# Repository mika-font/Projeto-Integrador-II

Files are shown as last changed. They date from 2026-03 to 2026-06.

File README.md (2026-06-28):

# Sensor RFID para Controle de Acesso

> Projeto integrante da disciplina Projeto Integrador II — Engenharia de Computação (UFSM).

Sistema de controle de acesso para laboratórios usando leitor RFID conectado a um ESP8266/ESP32. Suporta atualização remota (OTA) e registro básico de eventos.

## Sumário

- [Integrantes](#integrantes)
- [Objetivos](#objetivos)
- [Arquitetura](#arquitetura)
- [Hardware](#hardware)
- [Firmware](#firmware)
- [Instalação](#instalação)
- [Uso](#uso)
- [Estrutura do Projeto](#estrutura-do-projeto)
- [Em desenvolvimento](#em-desenvolvimento)

## Integrantes do Projeto

- Gabriel Schirmer
- Mikael Fontoura
- Raissa Brodt

## Objetivos

Os principais objetivos em desenvolvimento do projeto:

- Controlar o acesso ao laboratório usando um sistema RFID;
- Permitir atualização remota do *firmware* via OTA;
- Registrar eventos de acesso (autorizados e não autorizados);
- Criar uma interface de gerenciamento de tags;

## Arquitetura

Fluxo básico:

1. Tag aproximada ao leitor;
2. Leitor envia ID ao microcontrolador;
3. Microcontrolador verifica autorização;
4. Se autorizado: ativa a fechadura e registra evento;
5. Se não autorizado: registra tentativa e ignora;

## Hardware

Componentes principais:

- ESP8266 ou ESP32
- Leitor RFID (módulo RC522)
- Tags RFID compatíveis
- Fechadura solenóide
- Fonte 12V 3A
- Regulador de Tensão de 12V para 5V (L7805CV)
- Buzzer HNT-1205
- LED Verde e Vermelho
- Transistor TIP31C e Diodo 1N4007
- Resistores (1kΩ)

Pinagem de referência (ESP32):
- `D5` (GPIO2): Saída para relé/fechadura

## Firmware

Versões disponíveis:

- `code-esp8266/code-esp8266.ino` — implementação base para ESP8266
- `code-esp32/code-esp32.ino` — implementação base para ESP32 (Em Funcionamento)

Principais funcionalidades do firmware:

- Leitura de tag RFID via serial
- Lista local de tags autorizadas
- Acionamento da fechadura (pino `D5` no ESP32)
- Atualização OTA (ArduinoOTA)
- Logs básicos por serial (e opcionalmente via rede)

Dependências:

- `WiFi`
- `ArduinoOTA`
- `SPI` 
- `MFRC522`

---

## Instalação

Pré-requisitos:

- Arduino IDE
- Drivers USB (CH340/CP210x) instalados
- Placa ESP8266/ESP32 adicionada no Arduino IDE

Passos rápidos:

1. Abra o Arduino IDE
2. Instale as bibliotecas necessárias via Gerenciador de Placas
3. Para o ESP32, usamos uma URL adicional: "https://espressif.github.io/arduino-esp32/package_esp32_index.json"
4. Após adicionar essa URL, em Gerenciador de Placas, instale a biblioteca do ESP32
5. Selecione a placa apropriada em `Ferramentas → Placa`
6. Abra o código `code-esp8266/code-esp8266.ino` ou `code-esp32/code-esp32.ino`
7. Compile e faça o upload para o dispositivo

Configuração OTA: o firmware habilita `ArduinoOTA` — para usar, conecte o dispositivo à mesma rede do computador e selecione a porta de rede no IDE.

## Uso

1. Energize o sistema com a fonte adequada
2. Aproxime uma tag ao leitor
3. Observe o LED de status e o comportamento do relé
4. Verifique saídas seriais para logs e depuração

---

## Estrutura do Projeto

```
Projeto-Integrador-II/
├── README.md
├── code-esp8266/
├── code-esp32/
├── impressoes/
│   ├── porta_mdf/
│   └── caixas/
├── labflow-ct/
│   ├── backend/
│   ├── database/
│   ├── docs/
│   ├── frontend/
│   └── README.md
└── docs/
```

## Ferramentas Utilizadas

### Hardware e Firmware

- Arduino IDE — desenvolvimento e upload dos sketches
- Drivers USB: CH340 / CP210x
- Bibliotecas ESP32 usadas no firmware: `WiFi.h`, `ArduinoOTA.h`, `SPI.h`, `MFRC522.h` (ver `code-esp32/`)
- Software CAD para arquivos `.SLDPRT` / `.SLDASM`: SolidWorks 2024
- Software para `.DXF` : SolidWorks 2024 (exportação)
- Software para `.STL` : Ultimaker Cura 5.4.0

### Interface, Banco de Dados, Dashboard e Documentação

- Visual Studio Code — desenvolvimento de interface e scripts
- Software para Dashboard: Grafana
- Software para Banco de Dados: (definir)
- FrontEnd: (definir)
- BackEnd: (definir)
- Diagramas e Documentação: LucidChart, Google Docs e Canva

### Demais Ferramentas

- Git e GitHub — controle de versão e hospedagem do código

## Em desenvolvimento

- [x] Firmware base (ESP32)
- [x] Testes de campo com fechadura real
- [ ] Interface de gerenciamento de tags
- [ ] Registro remoto de logs (server)

Se você quiser contribuir, abra uma issue ou envie um pull request.

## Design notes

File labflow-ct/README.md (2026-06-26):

# LabFlow-CT

Software inicial para gerenciamento de cartões, usuários, laboratórios, dispositivos ESP32, permissões, firmware e logs de acesso.

## Stack

- Frontend: React + Vite + Recharts + Socket.IO Client
- Backend: Node.js + Express + MySQL + MQTT + Socket.IO
- Banco: MySQL
- Comunicação ESP32: MQTT

## Estrutura

```text
labflow-ct/
  backend/
  frontend/
  database/schema.sql
  docs/PORTAS_E_MQTT.md
```

## Login inicial

- Matrícula: `admin`
- Senha: `admin123`

Troque essa senha antes de usar em produção.

## Rodar localmente

### Banco

```bash
mysql -u root -p < database/schema.sql
```

Crie um usuário no MySQL, por exemplo:

```sql
CREATE USER 'labflow_user'@'localhost' IDENTIFIED BY 'labflow_pass';
GRANT ALL PRIVILEGES ON labflow_ct.* TO 'labflow_user'@'localhost';
FLUSH PRIVILEGES;
```

### Backend

```bash
cd backend
cp .env.example .env
npm install
npm run dev
```

### Frontend

```bash
cd frontend
cp .env.example .env
npm install
npm run dev
```

### MQTT local

Instale e rode Mosquitto. No Ubuntu:

```bash
sudo apt install mosquitto mosquitto-clients
sudo systemctl enable --now mosquitto
```

## Próximo passo recomendado

Este pacote é um MVP funcional. Para entrega final, recomenda-se complementar as telas de CRUD com formulários completos, validações de campos, upload real dos arquivos `.bin` de firmware e configuração de HTTPS/MQTT TLS.

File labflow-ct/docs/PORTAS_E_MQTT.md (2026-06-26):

# LabFlow-CT — Portas, MQTT e servidor

## Portas de comunicação

| Serviço | Porta padrão | Uso |
|---|---:|---|
| React/Vite em desenvolvimento | 5173 | Interface web local |
| Backend Node.js/Express | 3001 | API REST e WebSocket |
| MySQL | 3306 | Banco de dados |
| MQTT sem TLS | 1883 | Comunicação ESP32 ↔ servidor |
| MQTT com TLS | 8883 | MQTT seguro em produção |
| HTTP | 80 | Acesso público via Nginx |
| HTTPS | 443 | Acesso público seguro via Nginx |

## Tópicos MQTT sugeridos

Use `deviceId` como MAC address sem caracteres especiais ou um ID cadastrado no sistema.

### Pedido de acesso por cartão
ESP32 publica:

```json
Topic: labflow/{deviceId}/access/request
{
  "tokenAuth": "TOKEN_DO_DISPOSITIVO",
  "uid": "E6:97:A7:1A",
  "evento": "RFID_EXTERNO"
}
```

Servidor responde:

```json
Topic: labflow/{deviceId}/access/response
{
  "authorized": true,
  "reason": "PERMISSAO_VALIDA"
}
```

### Evento simples do dispositivo

```json
Topic: labflow/{deviceId}/event
{
  "tokenAuth": "TOKEN_DO_DISPOSITIVO",
  "evento": "BOTAO_EXTERNO_ATIVADO",
  "detalhe": "Modo livre ativado pelo leitor interno"
}
```

Eventos recomendados:

- `RFID_EXTERNO`
- `RFID_INTERNO`
- `BOTAO_EXTERNO`
- `BOTAO_INTERNO`
- `BOTAO_EXTERNO_ATIVADO`
- `BOTAO_EXTERNO_DESATIVADO`
- `STATUS`

### Checagem de firmware

```json
Topic: labflow/{deviceId}/firmware/check
{
  "tokenAuth": "TOKEN_DO_DISPOSITIVO",
  "firmwareAtual": "1.0.0"
}
```

Servidor responde:

```json
Topic: labflow/{deviceId}/firmware/response
{
  "update": true,
  "version": "1.1.0",
  "url": "https://servidor/firmware/labflow-1.1.0.bin",
  "obrigatorio": false
}
```

A regra implementada só libera atualização de firmware entre 00:00 e 06:59, evitando o período de aulas entre 7h e 23h.

## Subida no servidor

1. Instalar Node.js LTS, MySQL, Mosquitto e Nginx.
2. Criar o banco com `database/schema.sql`.
3. Criar usuário MySQL próprio para o projeto.
4. Copiar `backend/.env.example` para `backend/.env` e configurar credenciais.
5. Rodar backend com PM2 ou systemd.
6. Rodar `npm run build` no frontend e servir a pasta `dist` pelo Nginx.
7. Em produção, usar HTTPS na interface e MQTT com autenticação. Se possível, usar MQTT TLS na porta 8883.

## Comandos base Ubuntu Server

```bash
sudo apt update
sudo apt install -y mysql-server mosquitto mosquitto-clients nginx
curl -fsSL https://deb.nodesource.com/setup_lts.x | sudo -E bash -
sudo apt install -y nodejs
sudo npm install -g pm2
```

```bash
mysql -u root -p < database/schema.sql
```

```bash
cd backend
cp .env.example .env
npm install
npm run start
```

```bash
cd frontend
cp .env.example .env
npm install
npm run build
```

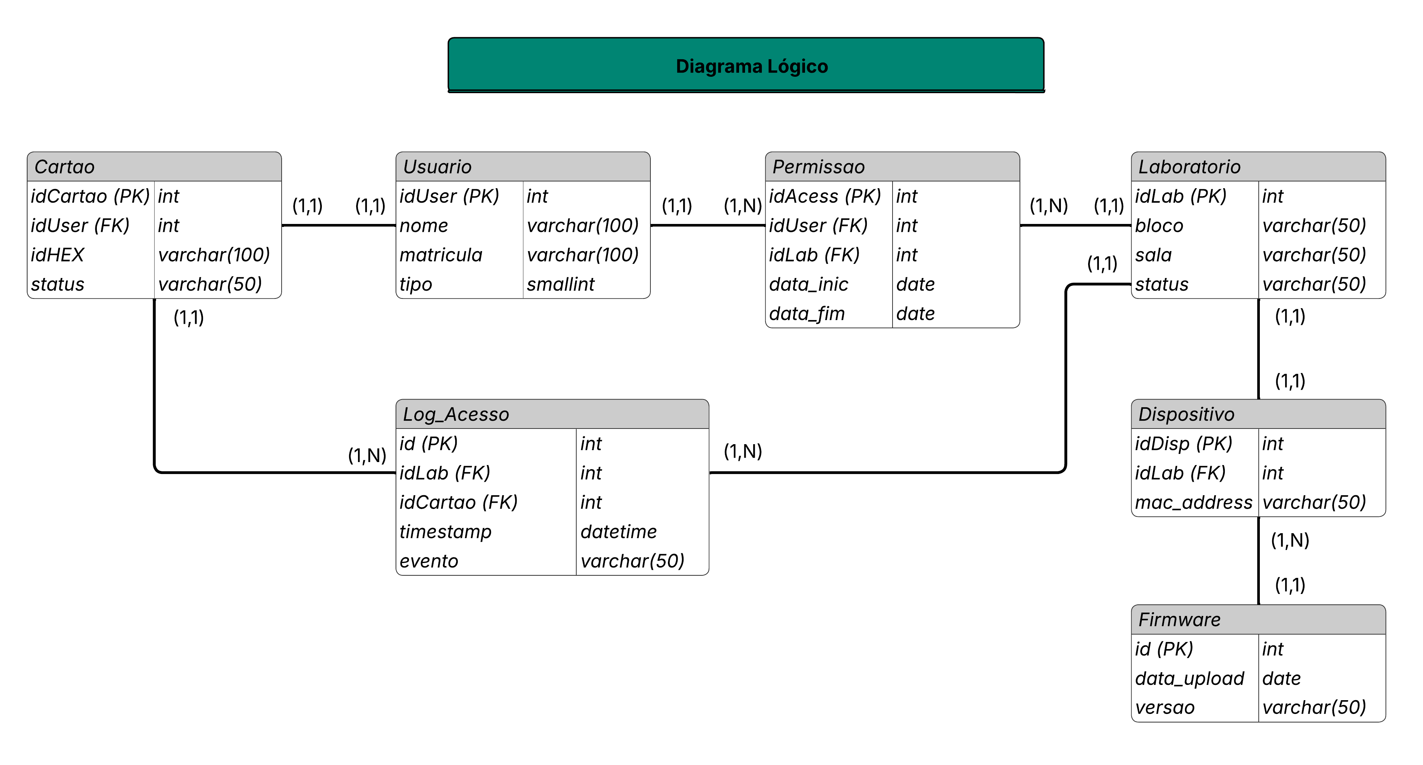
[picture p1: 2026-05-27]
docs/diagrama_Logico_BD.png

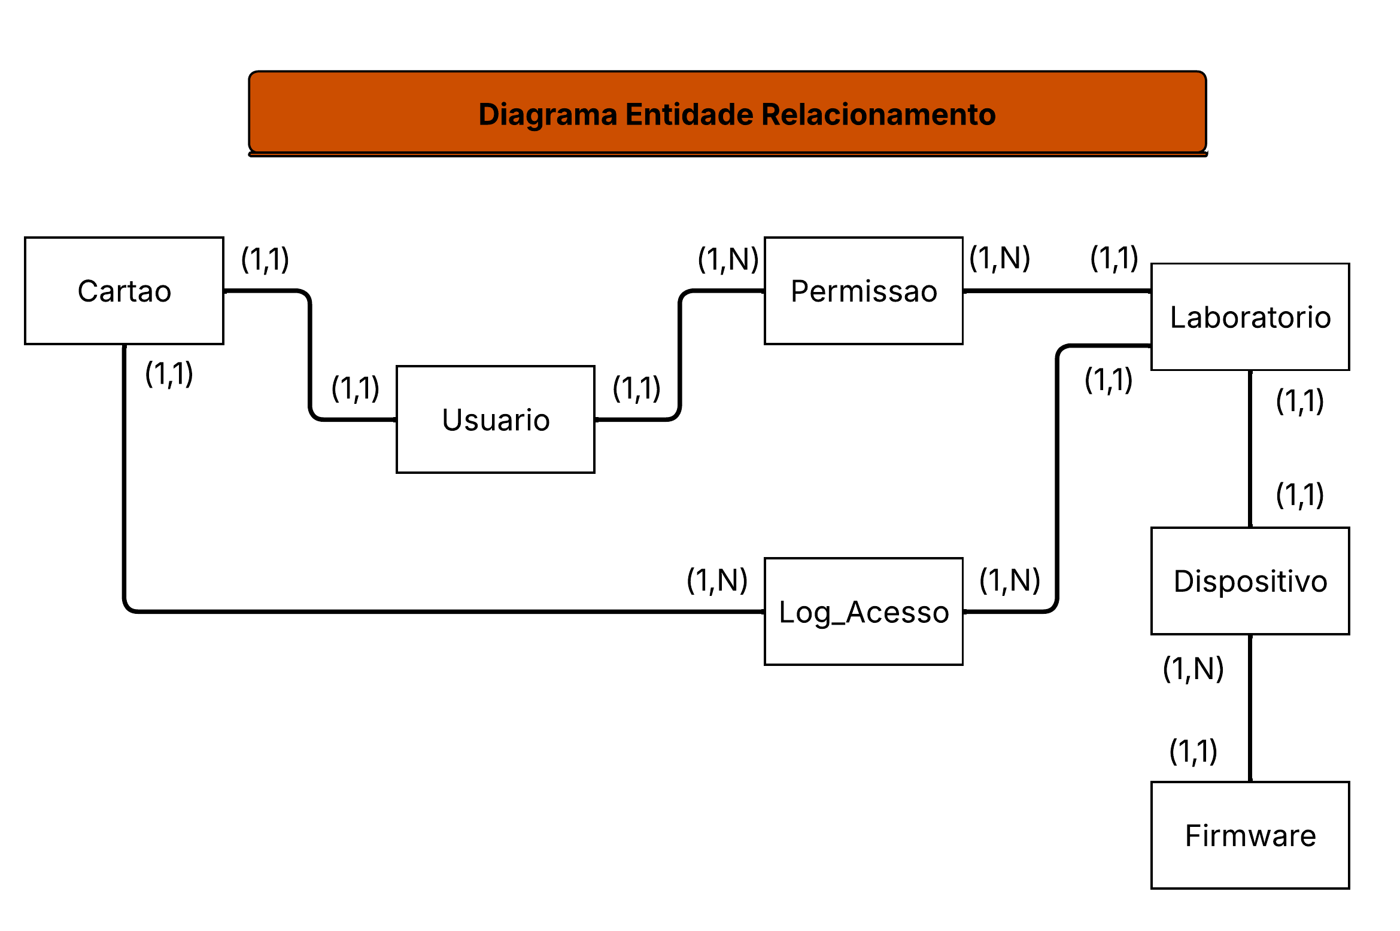
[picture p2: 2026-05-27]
docs/diagrama_Entidade_Relac_BD.png

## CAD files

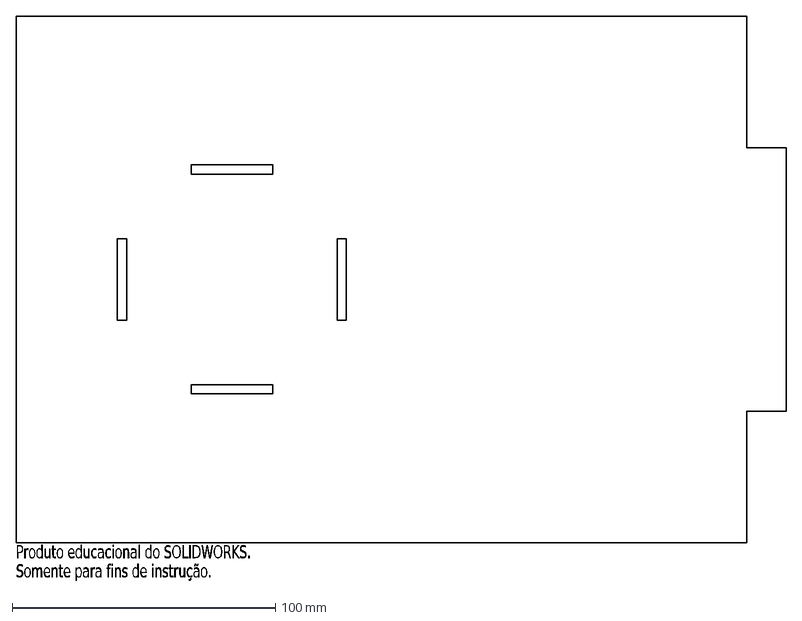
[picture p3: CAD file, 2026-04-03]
impressoes/baseP1.DXF
Produto educacional do SOLIDWORKS.
Somente para fins de instrução.

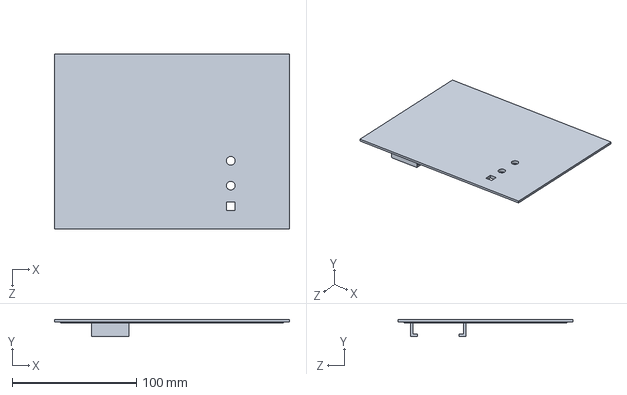
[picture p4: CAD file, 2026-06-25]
impressoes/caixas/tampaCaixaMaior.SLDPRT
189.0 x 14.0 x 141.0 mm

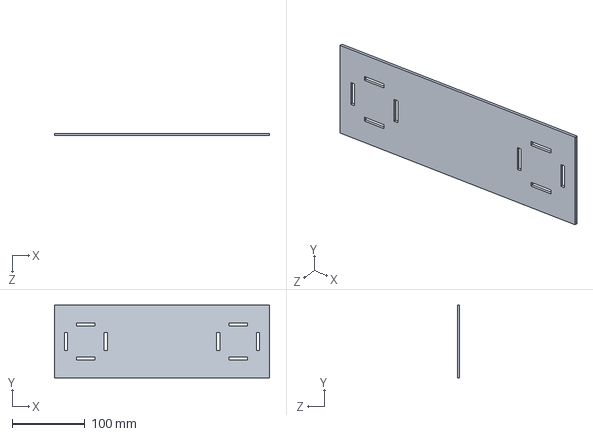
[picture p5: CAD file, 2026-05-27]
impressoes/porta_mdf/base.STEP
295.0 x 100.0 x 3.00 mm

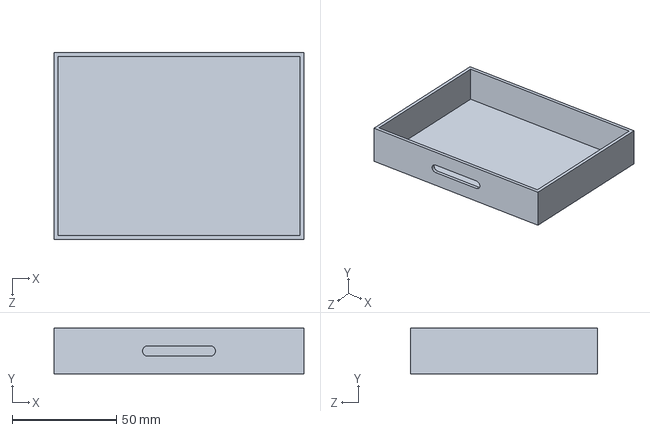
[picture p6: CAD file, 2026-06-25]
impressoes/caixas/caixaMenor.SLDPRT
120.0 x 22.0 x 90.0 mm

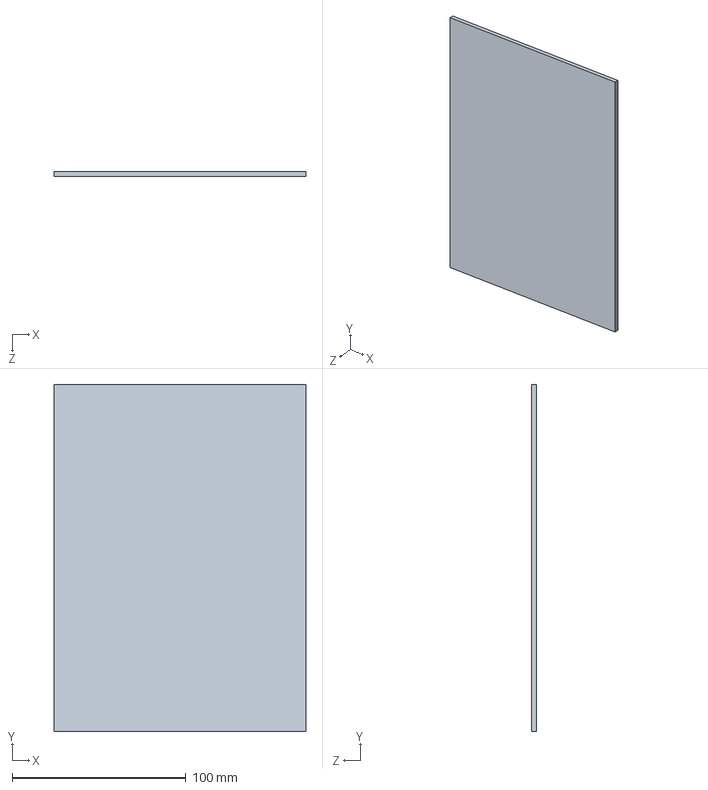
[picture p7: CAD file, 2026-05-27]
impressoes/porta_mdf/porta.STEP
145.0 x 200.0 x 3.00 mm

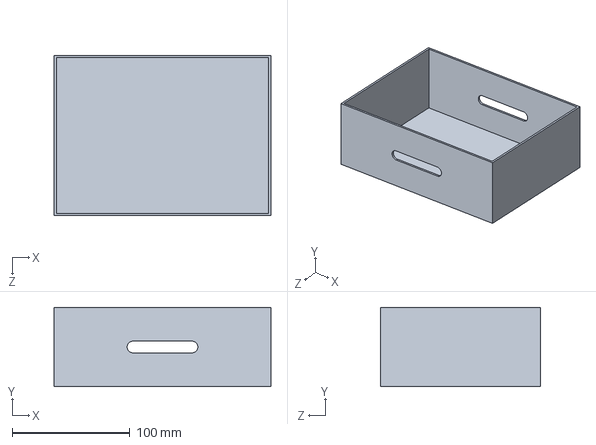
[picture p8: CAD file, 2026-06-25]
impressoes/caixas/caixaMaior.SLDPRT
184.0 x 67.0 x 136.0 mm

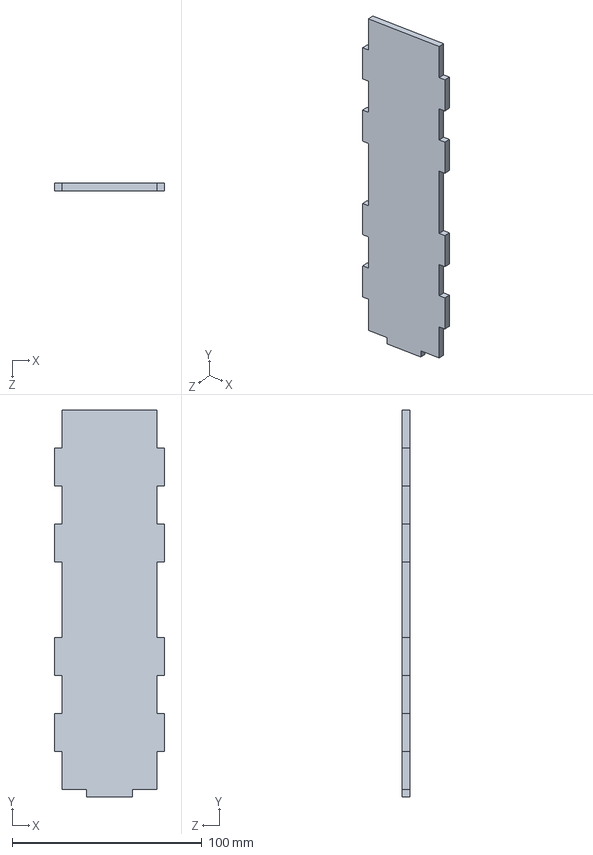
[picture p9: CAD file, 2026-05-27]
impressoes/porta_mdf/colunaDentado.STEP
58.0 x 204.0 x 4.00 mm

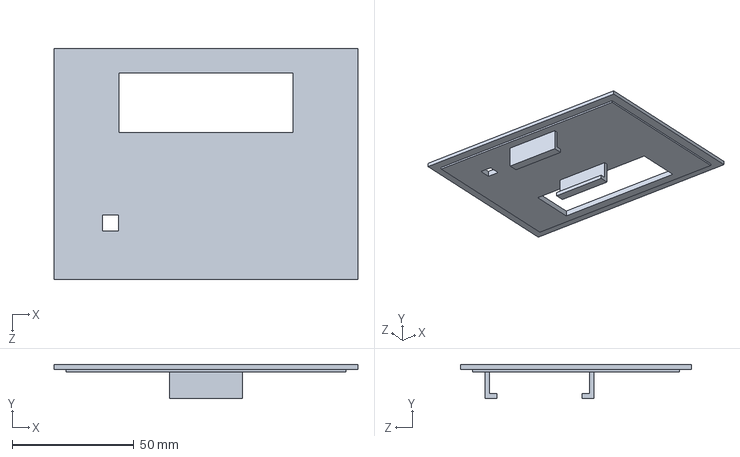
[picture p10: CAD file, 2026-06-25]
impressoes/caixas/tampaCaixaMenor.SLDPRT
125.0 x 14.0 x 95.0 mm

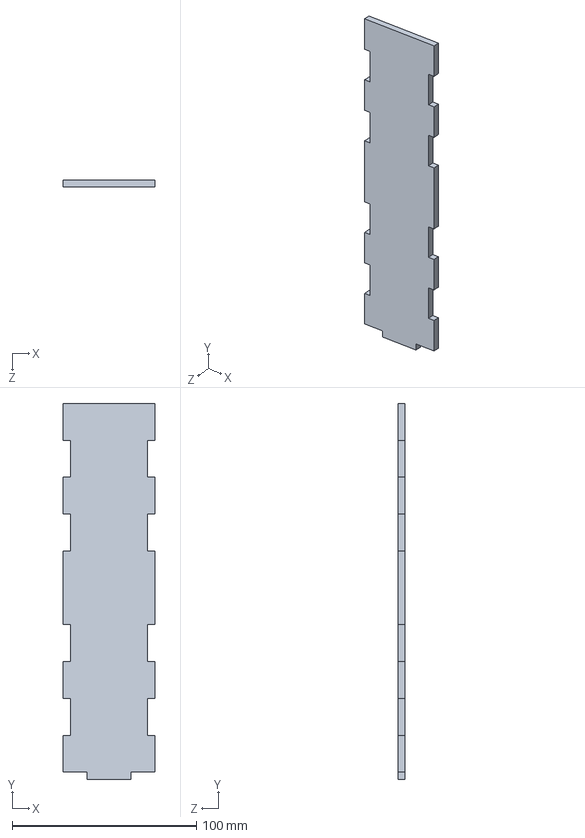
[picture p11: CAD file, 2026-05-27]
impressoes/porta_mdf/colunaVazado.STEP
50.0 x 204.0 x 4.00 mm

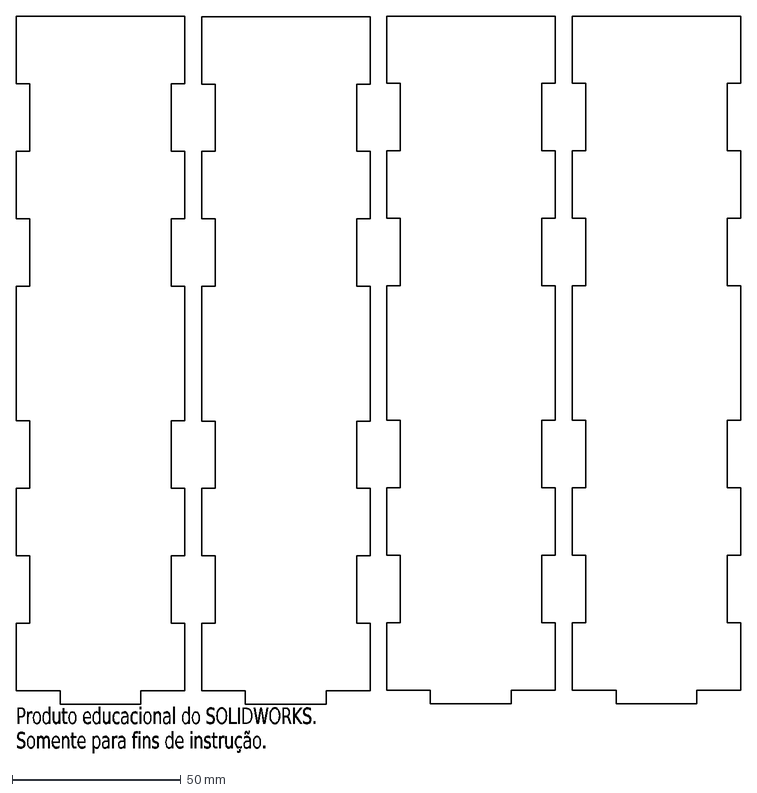
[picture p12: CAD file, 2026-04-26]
impressoes/porta_mdf/mont_4unid_col_vazada.DXF
Produto educacional do SOLIDWORKS.
Somente para fins de instrução.

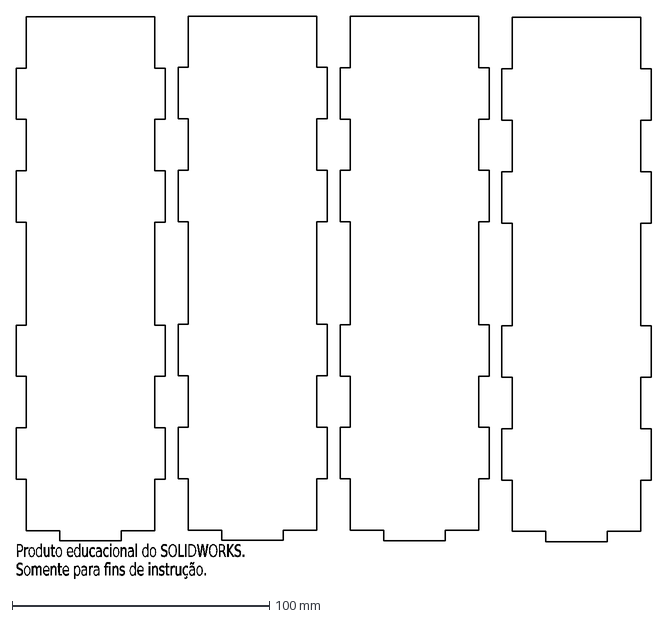
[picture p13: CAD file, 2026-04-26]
impressoes/porta_mdf/mont_4unid_col_dentada.DXF
Produto educacional do SOLIDWORKS.
Somente para fins de instrução.

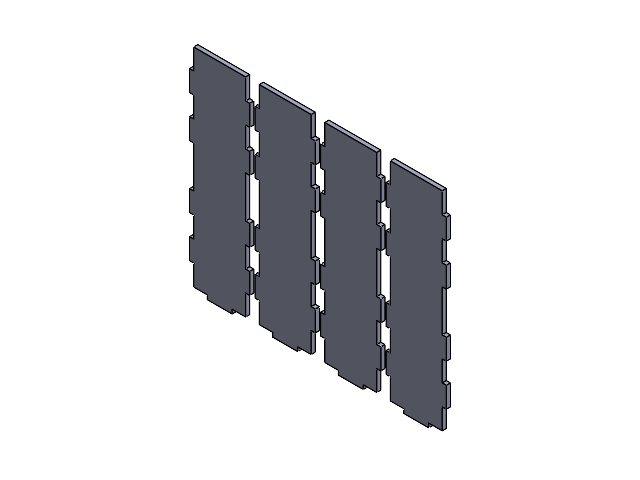
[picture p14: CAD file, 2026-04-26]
impressoes/porta_mdf/mont_colunas_dentadas.SLDASM
colunaDentado x 4

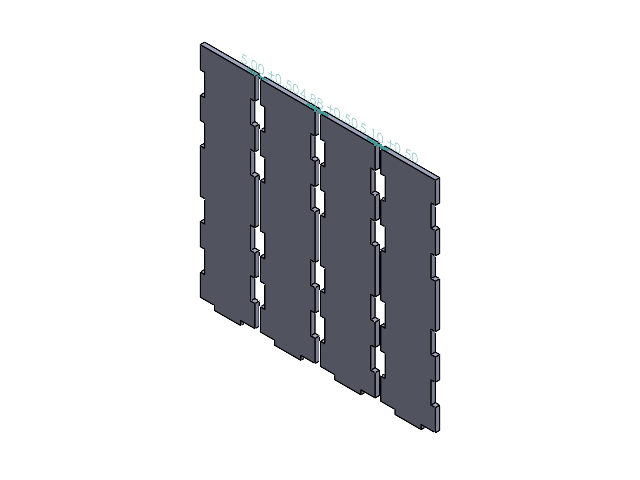
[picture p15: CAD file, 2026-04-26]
impressoes/porta_mdf/mont_colunas_vazadas.SLDASM
colunaVazado x 4

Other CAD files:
impressoes/caixas/caixaMaior.STL
impressoes/caixas/caixaMenor.STL
impressoes/caixas/tampaCaixaMaior.STL
impressoes/caixas/tampaCaixaMenor.STL
impressoes/porta_mdf/base.DXF
impressoes/porta_mdf/base.SLDPRT
impressoes/porta_mdf/colunaDentado.DXF
impressoes/porta_mdf/colunaDentado.SLDPRT
impressoes/porta_mdf/colunaVazado.DXF
impressoes/porta_mdf/colunaVazado.SLDPRT
impressoes/porta_mdf/porta.DXF
impressoes/porta_mdf/porta.SLDPRT

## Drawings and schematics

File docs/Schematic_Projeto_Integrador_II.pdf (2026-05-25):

A | A

1

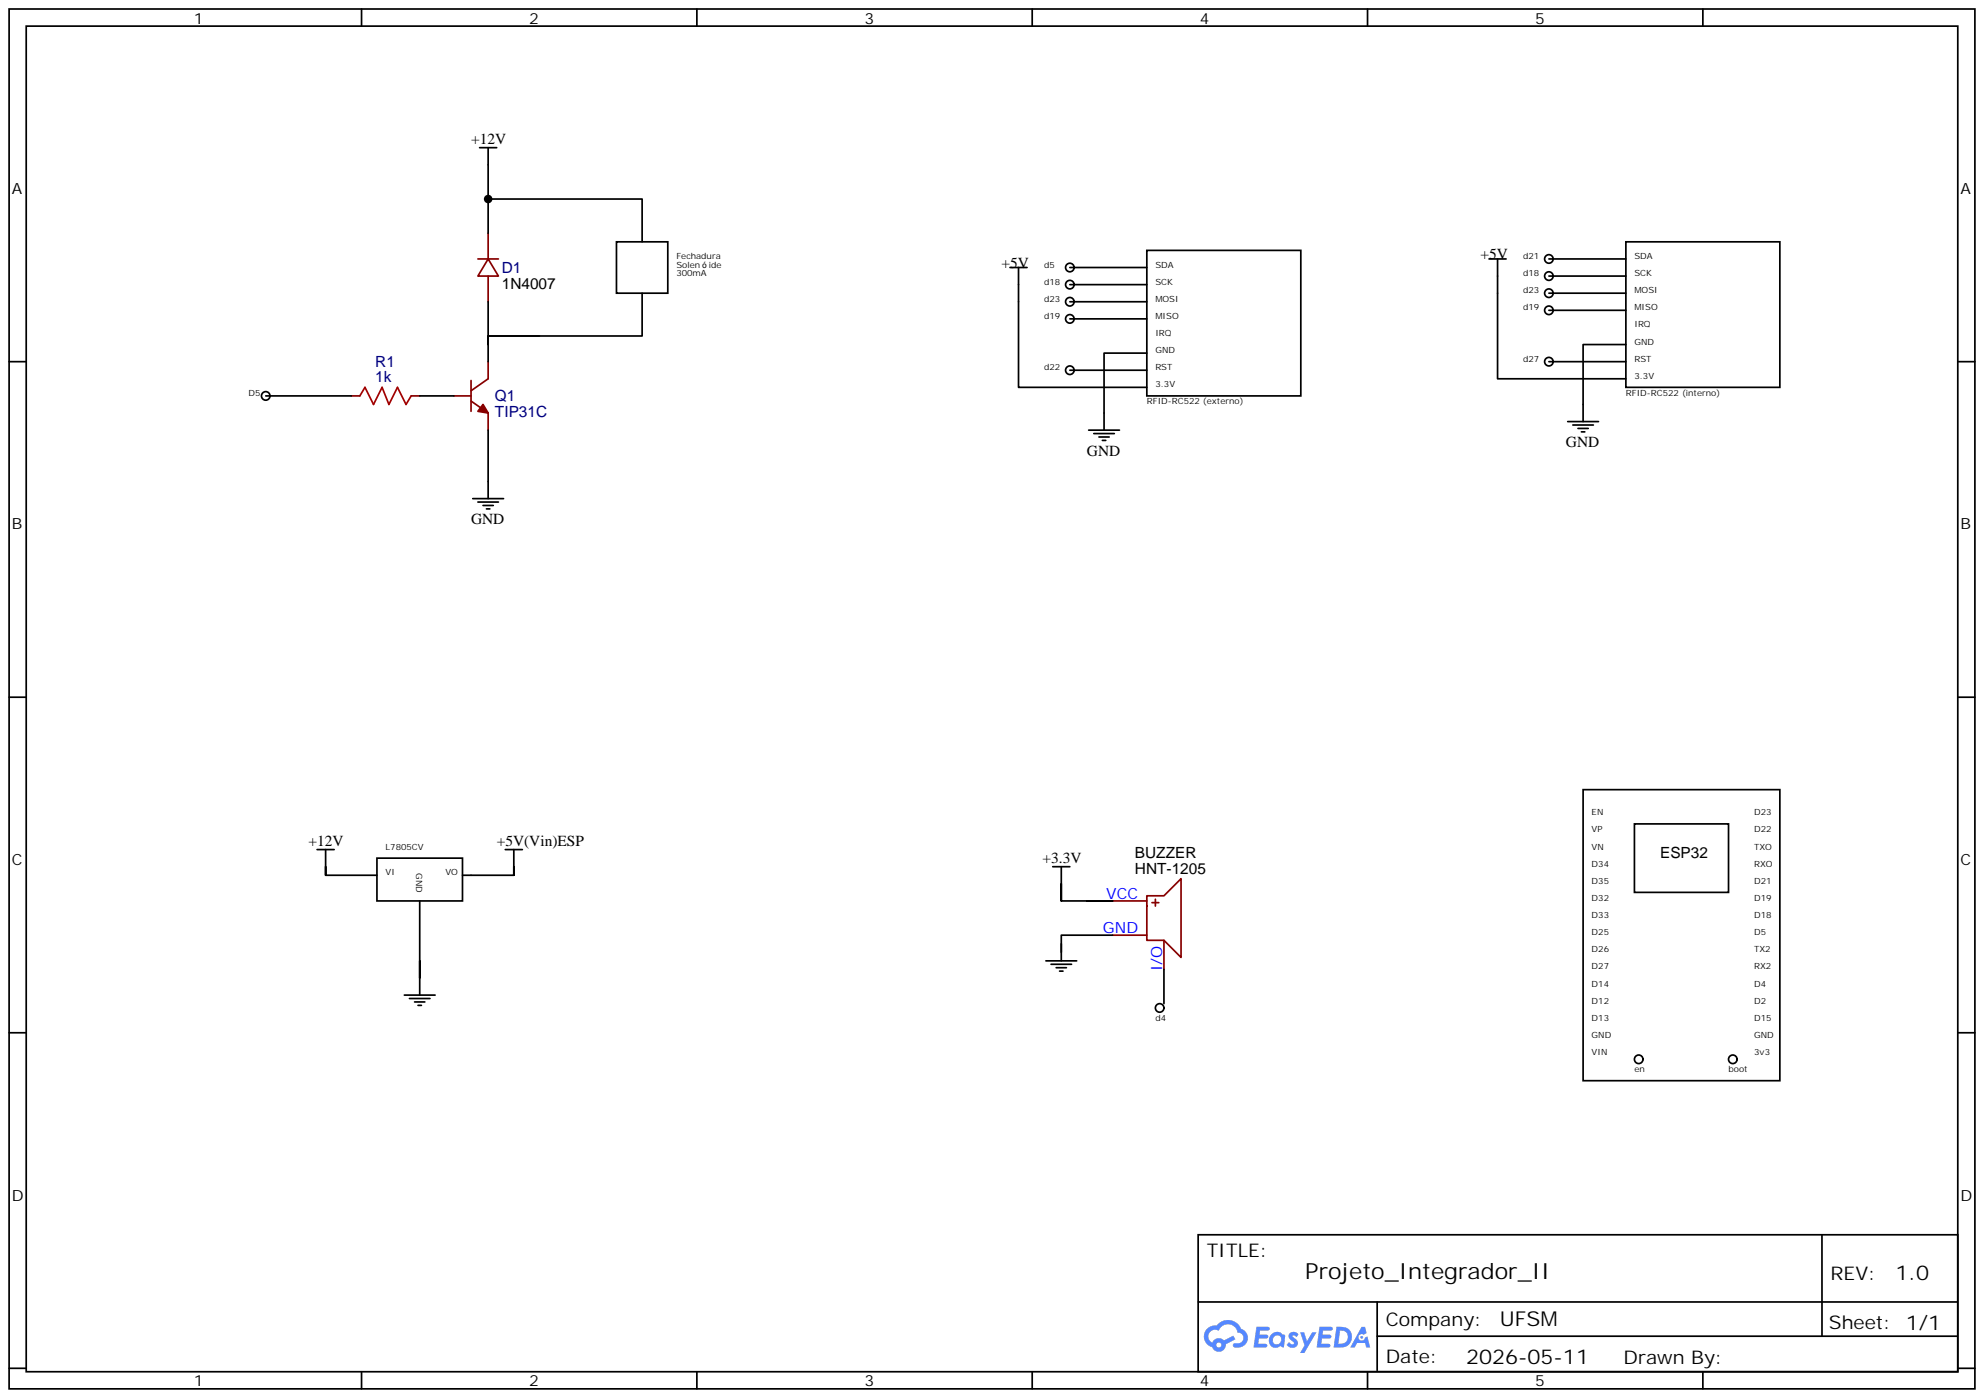
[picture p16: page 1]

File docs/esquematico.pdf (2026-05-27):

A | A

1

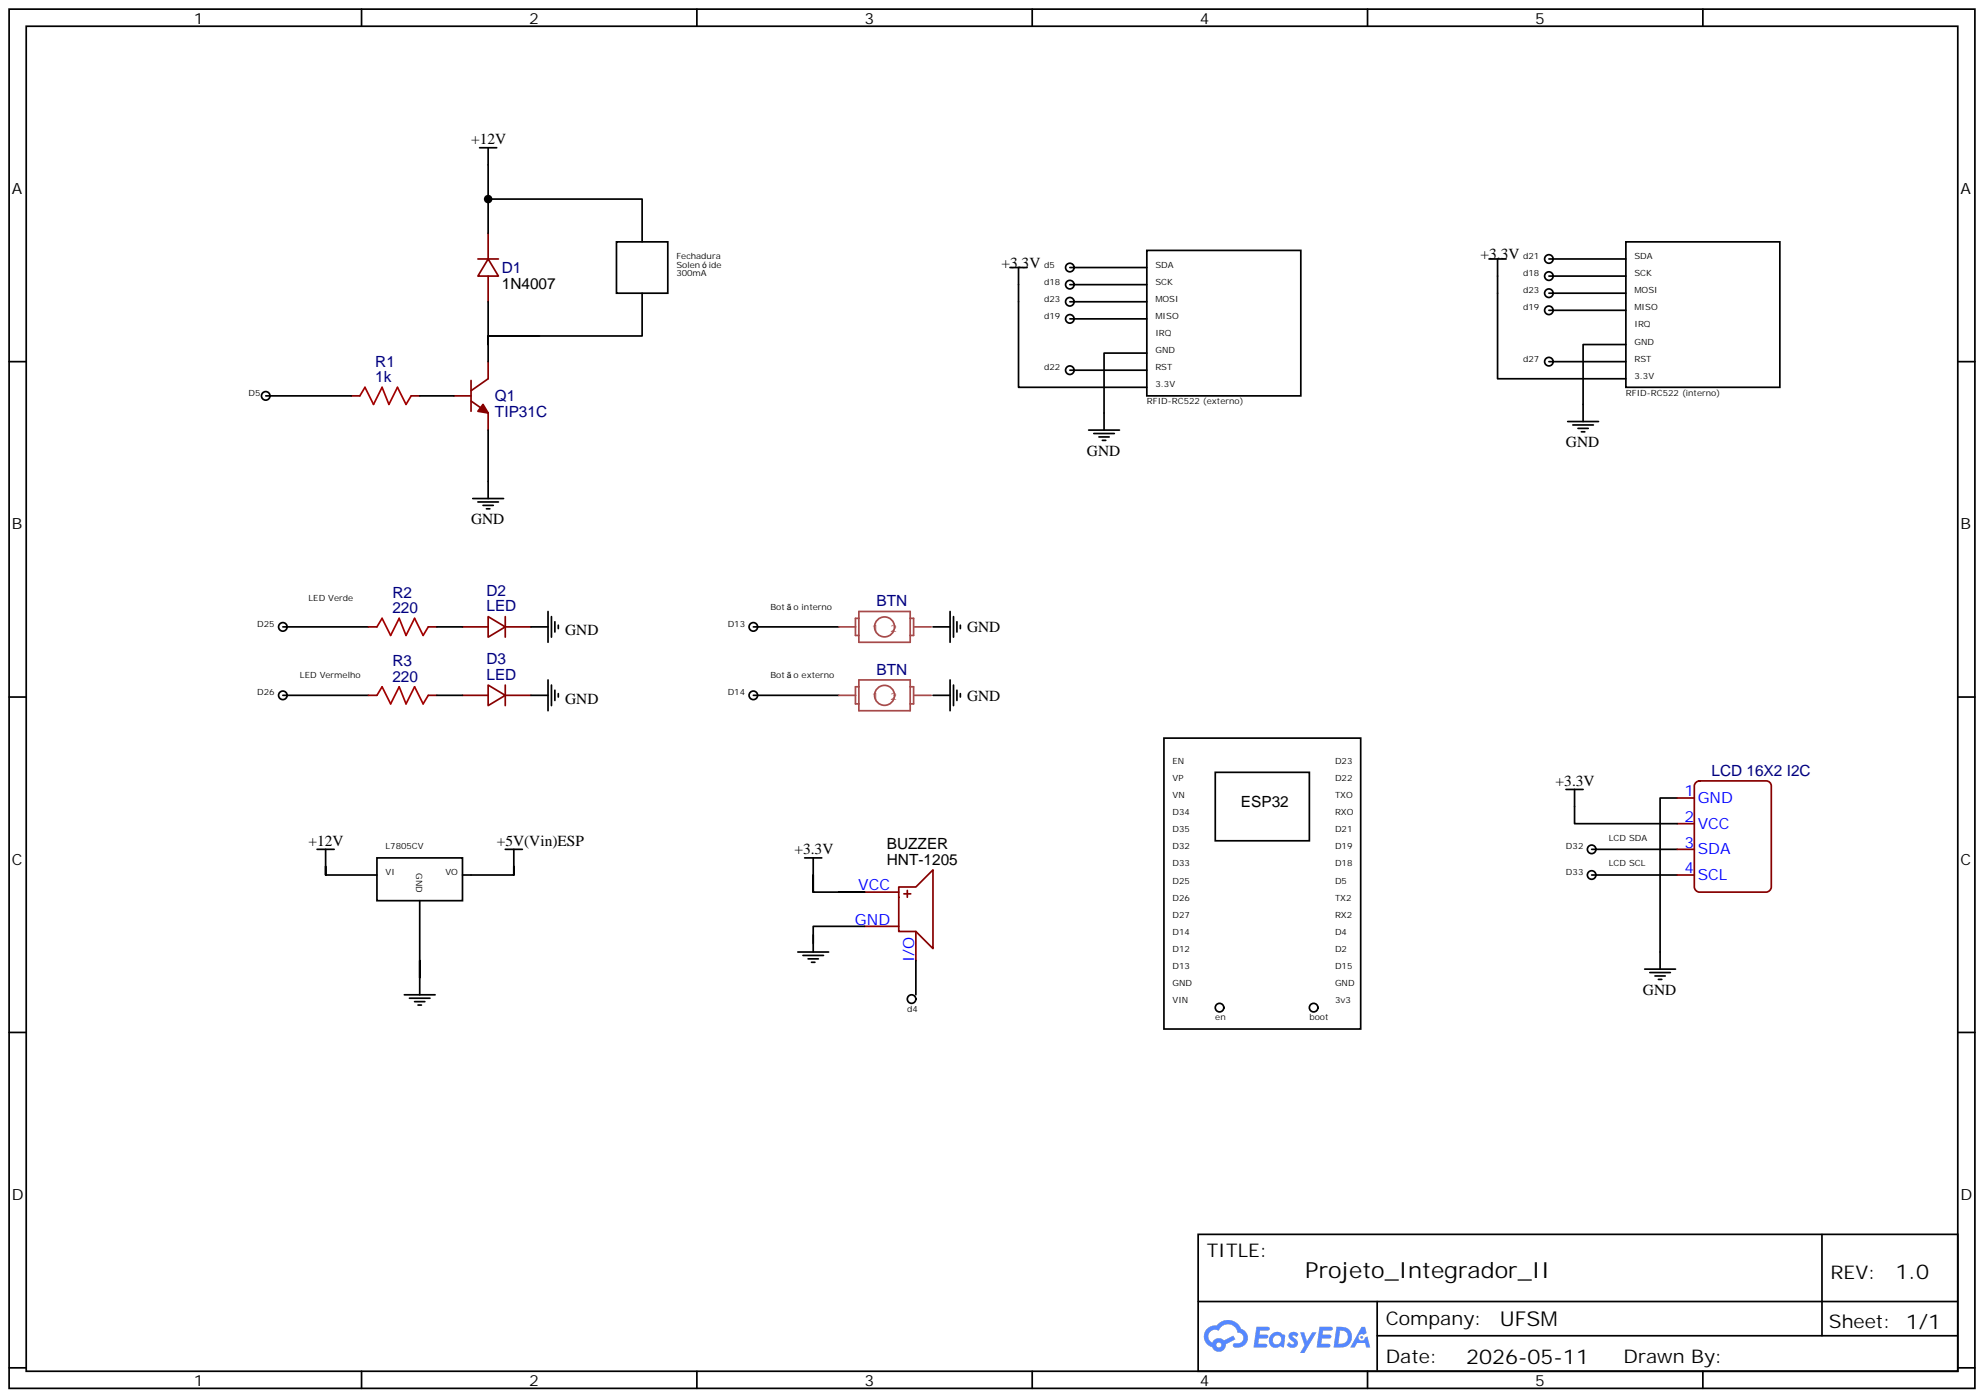
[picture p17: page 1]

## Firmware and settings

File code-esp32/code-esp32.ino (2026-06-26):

#include <WiFi.h>
#include <ArduinoOTA.h>
#include <SPI.h>
#include <MFRC522.h>
#include <Wire.h>
#include <LiquidCrystal_I2C.h>

#include <PubSubClient.h>
#include <ArduinoJson.h>

// ======================================================
// MQTT
// ======================================================
const char* mqtt_server = "192.168.3.23"; // IP do computador/servidor local
const int mqtt_port = 1883;

const char* deviceId = "1";
const char* tokenAuth = "labflow-token-esp32-001";

WiFiClient espClient;
PubSubClient mqtt(espClient);

// ======================================================
// LCD
// ======================================================
LiquidCrystal_I2C lcd(0x27, 16, 2);

// ======================================================
// WIFI
// ======================================================
const char* ssid = "Schirmer";
const char* password = "g254156325";

// ======================================================
// RFID EXTERNO
// ======================================================
#define SS_PIN_EXT 5
#define RST_PIN_EXT 22
MFRC522 rfidExt(SS_PIN_EXT, RST_PIN_EXT);

// ======================================================
// RFID INTERNO
// ======================================================
#define SS_PIN_INT 21
#define RST_PIN_INT 27
MFRC522 rfidInt(SS_PIN_INT, RST_PIN_INT);

// ======================================================
// BUZZER
// ======================================================
#define BUZZER 4

// ======================================================
// LEDS
// ======================================================
#define LED_GREEN 25
#define LED_RED   26

// ======================================================
// BOTÕES
// ======================================================
#define BUTTON 14       // Botão externo
#define BUTTON_EXIT 13  // Botão interno

// ======================================================
// FECHADURA
// ======================================================
#define LOCK 2 // GPIO da fechadura

// ======================================================
// CARTÃO UNIVERSAL
// ======================================================
const String CARTAO_UNIVERSAL = "F5 E2 39 D5"; // NUPEEDE

// ======================================================
// ESTADO
// ======================================================
bool modoLivre = false;
String ultimaOrigemConsulta = "";

// ======================================================
// CONTROLE DE LEITURA REPETIDA RFID
// ======================================================
String ultimoUIDLido = "";
String ultimoLeitorLido = "";
unsigned long tempoUltimaLeitura = 0;
const unsigned long intervaloMesmoCartao = 3000; // 3 segundos

// ======================================================
// PROTÓTIPOS
// ======================================================
void atualizarLCD();
void atualizarLEDs();
void bipCurto();
void bipErro();
void abrirPorta();
void conectarMQTT();
void enviarEvento(String evento, String descricao);
void enviarTentativaAcesso(String uidHex, String origem);
String uidToString(byte *uid, byte size);
bool leituraRepetida(String uidHex, String leitor);
void alternarModoLivre(String origem);
void mqttCallback(char* topic, byte* payload, unsigned int length);

// ======================================================
// FUNÇÕES DE INTERFACE
// ======================================================
void atualizarLEDs() {
  if (modoLivre) {
    digitalWrite(LED_GREEN, HIGH);
    digitalWrite(LED_RED, LOW);
  } else {
    digitalWrite(LED_GREEN, LOW);
    digitalWrite(LED_RED, HIGH);
  }
}

void atualizarLCD() {
  lcd.clear();

  if (modoLivre) {
    lcd.setCursor(0, 0);
    lcd.print("SALA ABERTA");

    lcd.setCursor(0, 1);
    lcd.print("Botao Liberado");
  } else {
    lcd.setCursor(0, 0);
    lcd.print("SALA FECHADA");

    lcd.setCursor(0, 1);
    lcd.print("Aguardando...");
  }
}

void bipCurto() {
  digitalWrite(BUZZER, LOW);
  delay(200);
  digitalWrite(BUZZER, HIGH);
}

void bipErro() {
  for (int i = 0; i < 2; i++) {
    digitalWrite(BUZZER, LOW);
    delay(150);
    digitalWrite(BUZZER, HIGH);
    delay(150);
  }
}

void abrirPorta() {
  bipCurto();

  lcd.clear();
  lcd.setCursor(0, 0);
  lcd.print("PORTA ABERTA");

  lcd.setCursor(0, 1);
  lcd.print("Acesso Liberado");

  digitalWrite(LOCK, HIGH);

  delay(3000);

  digitalWrite(LOCK, LOW);

  atualizarLCD();
}

void alternarModoLivre(String origem) {
  modoLivre = !modoLivre;

  atualizarLEDs();

  lcd.clear();

  if (modoLivre) {
    Serial.println("MODO LIVRE ATIVADO");

    lcd.setCursor(0, 0);
    lcd.print("SALA ABERTA");

    lcd.setCursor(0, 1);
    lcd.print(origem);
  } else {
    Serial.println("MODO LIVRE DESATIVADO");

    lcd.setCursor(0, 0);
    lcd.print("SALA FECHADA");

    lcd.setCursor(0, 1);
    lcd.print(origem);
  }

  bipCurto();

  delay(1000);
  atualizarLCD();
}

// ======================================================
// FUNÇÕES RFID
// ======================================================
String uidToString(byte *uid, byte size) {
  String uidString = "";

  for (byte i = 0; i < size; i++) {
    if (uid[i] < 0x10) {
      uidString += "0";
    }

    uidString += String(uid[i], HEX);

    if (i < size - 1) {
      uidString += " ";
    }
  }

  uidString.toUpperCase();
  return uidString;
}

bool leituraRepetida(String uidHex, String leitor) {
  unsigned long agora = millis();

  if (uidHex == ultimoUIDLido &&
      leitor == ultimoLeitorLido &&
      agora - tempoUltimaLeitura < intervaloMesmoCartao) {
    Serial.println("Leitura repetida ignorada");
    return true;
  }

  ultimoUIDLido = uidHex;
  ultimoLeitorLido = leitor;
  tempoUltimaLeitura = agora;

  return false;
}

// ======================================================
// MQTT
// ======================================================
void conectarMQTT() {
  while (!mqtt.connected()) {
    Serial.print("Conectando ao MQTT... ");

    String clientId = "ESP32-LabFlow-" + String(deviceId);

    if (mqtt.connect(clientId.c_str())) {
      Serial.println("conectado!");

      String responseTopic = "labflow/" + String(deviceId) + "/access/response";
      mqtt.subscribe(responseTopic.c_str());

      String firmwareTopic = "labflow/" + String(deviceId) + "/firmware/response";
      mqtt.subscribe(firmwareTopic.c_str());

      String statusTopic = "labflow/" + String(deviceId) + "/status";

      StaticJsonDocument<128> doc;
      doc["tokenAuth"] = tokenAuth;
      doc["status"] = "ONLINE";

      char buffer[128];
      serializeJson(doc, buffer);

      mqtt.publish(statusTopic.c_str(), buffer);

      Serial.print("Inscrito em: ");
      Serial.println(responseTopic);

    } else {
      Serial.print("falhou. Codigo: ");
      Serial.println(mqtt.state());
      delay(3000);
    }
  }
}

void enviarEvento(String evento, String descricao) {
  if (!mqtt.connected()) {
    conectarMQTT();
  }

  StaticJsonDocument<256> doc;

  doc["tokenAuth"] = tokenAuth;
  doc["evento"] = evento;
  doc["descricao"] = descricao;

  char buffer[256];
  serializeJson(doc, buffer);

  String topic = "labflow/" + String(deviceId) + "/event";

  mqtt.publish(topic.c_str(), buffer);

  Serial.print("Evento enviado para ");
  Serial.print(topic);
  Serial.print(": ");
  Serial.println(buffer);
}

void enviarTentativaAcesso(String uidHex, String origem) {
  if (!mqtt.connected()) {
    conectarMQTT();
  }

  ultimaOrigemConsulta = origem;

  StaticJsonDocument<256> doc;

  doc["tokenAuth"] = tokenAuth;
  doc["uid"] = uidHex;
  doc["origem"] = origem;
  doc["evento"] = origem;

  char buffer[256];
  serializeJson(doc, buffer);

  String topic = "labflow/" + String(deviceId) + "/access/request";

  mqtt.publish(topic.c_str(), buffer);

  Serial.print("Tentativa enviada para ");
  Serial.print(topic);
  Serial.print(": ");
  Serial.println(buffer);

  lcd.clear();
  lcd.setCursor(0, 0);
  lcd.print("Verificando...");

  lcd.setCursor(0, 1);
  if (origem == "RFID_INTERNO") {
    lcd.print("Cartao Interno");
  } else {
    lcd.print("Cartao Externo");
  }
}

void mqttCallback(char* topic, byte* payload, unsigned int length) {
  String mensagem;

  for (unsigned int i = 0; i < length; i++) {
    mensagem += (char)payload[i];
  }

  Serial.print("Mensagem recebida em ");
  Serial.print(topic);
  Serial.print(": ");
  Serial.println(mensagem);

  StaticJsonDocument<256> doc;
  DeserializationError erro = deserializeJson(doc, mensagem);

  if (erro) {
    Serial.println("Erro ao interpretar JSON MQTT");
    return;
  }

  String topico = String(topic);

  if (topico.endsWith("/access/response")) {
    bool authorized = doc["authorized"] | false;
    const char* reason = doc["reason"] | "";

    Serial.print("Resposta acesso: ");
    Serial.println(reason);

    if (authorized) {
      if (ultimaOrigemConsulta == "RFID_EXTERNO") {
        Serial.println("SERVIDOR LIBEROU RFID EXTERNO");

        lcd.clear();
        lcd.setCursor(0, 0);
        lcd.print("ACESSO LIBERADO");
        lcd.setCursor(0, 1);
        lcd.print("Servidor OK");

        abrirPorta();

      } else if (ultimaOrigemConsulta == "RFID_INTERNO") {
        Serial.println("SERVIDOR LIBEROU RFID INTERNO");

        alternarModoLivre("Servidor OK");

      } else {
        Serial.println("Origem desconhecida na resposta MQTT");
      }

    } else {
      Serial.println("SERVIDOR NEGOU ACESSO");

      lcd.clear();
      lcd.setCursor(0, 0);
      lcd.print("ACESSO NEGADO");

      lcd.setCursor(0, 1);
      lcd.print(reason);

      bipErro();

      delay(1000);
      atualizarLCD();
    }

    ultimaOrigemConsulta = "";
  }
}

// ======================================================
// SETUP
// ======================================================
void setup() {
  Serial.begin(9600);

  // LCD
  Wire.begin(32, 33);

  lcd.init();
  lcd.backlight();

  lcd.setCursor(0, 0);
  lcd.print("Sistema OK");

  // Buzzer
  pinMode(BUZZER, OUTPUT);
  digitalWrite(BUZZER, HIGH);

  // Fechadura
  pinMode(LOCK, OUTPUT);
  digitalWrite(LOCK, LOW);

  // LEDs
  pinMode(LED_GREEN, OUTPUT);
  pinMode(LED_RED, OUTPUT);

  // Botões
  pinMode(BUTTON, INPUT_PULLUP);
  pinMode(BUTTON_EXIT, INPUT_PULLUP);

  atualizarLEDs();

  // SPI padrão do ESP32
  // SCK = 18
  // MISO = 19
  // MOSI = 23
  SPI.begin();

  // Configura SS dos dois leitores
  pinMode(SS_PIN_EXT, OUTPUT);
  pinMode(SS_PIN_INT, OUTPUT);

  // Desativa ambos inicialmente
  digitalWrite(SS_PIN_EXT, HIGH);
  digitalWrite(SS_PIN_INT, HIGH);

  // Inicializa RFID externo
  digitalWrite(SS_PIN_EXT, LOW);
  rfidExt.PCD_Init();
  digitalWrite(SS_PIN_EXT, HIGH);

  // Inicializa RFID interno
  digitalWrite(SS_PIN_INT, LOW);
  rfidInt.PCD_Init();
  digitalWrite(SS_PIN_INT, HIGH);

  Serial.println("Sistema iniciado");

  // Wi-Fi
  WiFi.begin(ssid, password);
  Serial.print("Conectando WiFi");

  while (WiFi.status() != WL_CONNECTED) {
    delay(500);
    Serial.print(".");
  }

  Serial.println();
  Serial.println("WiFi conectado!");
  Serial.print("IP da ESP32: ");
  Serial.println(WiFi.localIP());

  // MQTT
  mqtt.setServer(mqtt_server, mqtt_port);
  mqtt.setCallback(mqttCallback);

  conectarMQTT();

  // OTA
  ArduinoOTA.setPassword("srm");
  ArduinoOTA.begin();

  Serial.println("OTA pronto!");

  // LCD inicial
  lcd.clear();

  lcd.setCursor(0, 0);
  lcd.print("WiFi OK");

  lcd.setCursor(0, 1);
  lcd.print(WiFi.localIP());

  delay(5000);
  atualizarLCD();
}

// ======================================================
// LOOP
// ======================================================
void loop() {
  ArduinoOTA.handle();

  if (!mqtt.connected()) {
    conectarMQTT();
  }

  mqtt.loop();

  // ====================================================
  // TESTA RFID INTERNO
  // ====================================================
  digitalWrite(SS_PIN_EXT, HIGH);
  digitalWrite(SS_PIN_INT, LOW);

  if (rfidInt.PICC_IsNewCardPresent() && rfidInt.PICC_ReadCardSerial()) {
    String uidHex = uidToString(rfidInt.uid.uidByte, rfidInt.uid.size);

    Serial.print("UID interno: ");
    Serial.println(uidHex);

    if (leituraRepetida(uidHex, "RFID_INTERNO")) {
      rfidInt.PICC_HaltA();
      rfidInt.PCD_StopCrypto1();
      digitalWrite(SS_PIN_INT, HIGH);
      return;
    }

    if (uidHex == CARTAO_UNIVERSAL) {
      Serial.println("CARTAO UNIVERSAL NO RFID INTERNO");

      alternarModoLivre("Cartao Universal");

    } else {
      enviarTentativaAcesso(uidHex, "RFID_INTERNO");
    }

    rfidInt.PICC_HaltA();
    rfidInt.PCD_StopCrypto1();
  }

  digitalWrite(SS_PIN_INT, HIGH);

  // ====================================================
  // BOTÃO EXTERNO
  // Funciona apenas se modoLivre estiver ativo
  // ====================================================
  if (modoLivre && digitalRead(BUTTON) == LOW) {
    Serial.println("BOTAO EXTERNO PRESSIONADO");

    enviarEvento("BOTAO_EXTERNO", "Porta aberta pelo botao externo em modo livre");

    abrirPorta();

    while (digitalRead(BUTTON) == LOW) {
      delay(10);
    }

    delay(200);
  }

  // ====================================================
  // BOTÃO INTERNO
  // Sempre abre a porta
  // ====================================================
  if (digitalRead(BUTTON_EXIT) == LOW) {
    Serial.println("BOTAO INTERNO PRESSIONADO");

    enviarEvento("BOTAO_INTERNO", "Porta aberta pelo botao interno");

    abrirPorta();

    while (digitalRead(BUTTON_EXIT) == LOW) {
      delay(10);
    }

    delay(200);
  }

  // ====================================================
  // TESTA RFID EXTERNO
  // ====================================================
  digitalWrite(SS_PIN_INT, HIGH);
  digitalWrite(SS_PIN_EXT, LOW);

  if (rfidExt.PICC_IsNewCardPresent() && rfidExt.PICC_ReadCardSerial()) {
    String uidHex = uidToString(rfidExt.uid.uidByte, rfidExt.uid.size);

    Serial.print("UID externo: ");
    Serial.println(uidHex);

    if (leituraRepetida(uidHex, "RFID_EXTERNO")) {
      rfidExt.PICC_HaltA();
      rfidExt.PCD_StopCrypto1();
      digitalWrite(SS_PIN_EXT, HIGH);
      return;
    }

    if (uidHex == CARTAO_UNIVERSAL) {
      Serial.println("CARTAO UNIVERSAL NO RFID EXTERNO");

      lcd.clear();
      lcd.setCursor(0, 0);
      lcd.print("ACESSO LIBERADO");

      lcd.setCursor(0, 1);
      lcd.print("Cartao Universal");

      abrirPorta();

      delay(1000);
      atualizarLCD();

    } else {
      enviarTentativaAcesso(uidHex, "RFID_EXTERNO");
    }

    rfidExt.PICC_HaltA();
    rfidExt.PCD_StopCrypto1();
  }

  digitalWrite(SS_PIN_EXT, HIGH);
}

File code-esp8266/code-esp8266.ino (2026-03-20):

#include <ESP8266WiFi.h>
#include <ESP8266mDNS.h>
#include <WiFiUdp.h>
#include <ArduinoOTA.h>

const char* ssid = "TauraBots";
const char* password = "robotica2024";

void setup() {
  pinMode(D4, OUTPUT);
  Serial.begin(115200);
  Serial.println("Iniciando...");
  WiFi.mode(WIFI_STA);
  WiFi.begin(ssid, password);
  while (WiFi.waitForConnectResult() != WL_CONNECTED) {
    Serial.println("Conexao falhou! Reiniciando...");
    delay(5000);
    ESP.restart();
  }

  ArduinoOTA.onStart([]() {
    Serial.println("Inicio...");
  });
  ArduinoOTA.onEnd([]() {
    Serial.println("nFim!");
  });
  ArduinoOTA.onProgress([](unsigned int progress, unsigned int total) {
    Serial.printf("Progresso: %u%%r", (progress / (total / 100)));
  });
  ArduinoOTA.onError([](ota_error_t error) {
    Serial.printf("Erro [%u]: ", error);
    if (error == OTA_AUTH_ERROR) Serial.println("Autenticacao Falhou");
    else if (error == OTA_BEGIN_ERROR) Serial.println("Falha no Inicio");
    else if (error == OTA_CONNECT_ERROR) Serial.println("Falha na Conexao");
    else if (error == OTA_RECEIVE_ERROR) Serial.println("Falha na Recepcao");
    else if (error == OTA_END_ERROR) Serial.println("Falha no Fim");
  });
  ArduinoOTA.begin();
  Serial.println("Pronto");
  Serial.print("Endereco IP: ");
  Serial.println(WiFi.localIP());
}

void loop() {
  ArduinoOTA.handle();
  digitalWrite(D4, HIGH); // Aciona sinal 2
  delay(2000); // Espera por 2 segundos
  digitalWrite(D4, LOW); // Apaga sinal 2
  delay(2000);  // Espera por 2 segundos
}

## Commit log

2026-03-31 Modelagem 3D da Porta, Base e Colunas
    [base.SLDPRT, colunaEncaixe.SLDPRT, colunaVazado.SLDPRT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]
2026-04-03 Reconfiguração da porta em MDF e arquivos dxf
    [base.SLDPRT, baseP1.DXF, baseP1.SLDPRT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]
2026-04-22 Correção das medidas
    [base.DXF, base.SLDPRT, baseP1.SLDPRT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]
2026-04-22 Correção das Medidas 2.0
    [baset.SLDPRT]
2026-04-26 Adição de montagem com as 4 colunas
    [mont_4unid_col_dentada.DXF, mont_4unid_col_vazada.DXF, mont_colunas_dentadas.SLDASM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]
2026-05-07 add esp32 principal code
2026-05-23 Esquemático do circuito
2026-05-27 Esquemático do Circuito 2: add Display LCD e botão interno
2026-05-27 [UPD]: Organização dos arquivos da porta e adição dos diagramas de banco de dados
    [base.DXF, base.SLDPRT, base.STEP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]
2026-06-22 Caixas para guardar o projeto
    [caixaMaior.SLDPRT, caixaMaior.STL, caixaMenor.SLDPRT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]
2026-06-25 Versão 2.0 das Caixa
    [caixaMaior.SLDPRT, caixaMaior.STL, caixaMenor.SLDPRT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]
